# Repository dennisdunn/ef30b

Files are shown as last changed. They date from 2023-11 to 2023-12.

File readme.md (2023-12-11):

# EF-30B-disp Driver
This project repurposes a blown **EF-30B-disp** display board taken from
an electric fireplace as an I2C-addressable panel. The panel
consists of five LEDs and a two digit, 7-segment module. 

The original, blown, driver chip on the display board was
removed and replaced with 2, 8-pin, male headers. The four pin
interface socket was replaced with a 4-pin, right-angled, male
header.

The 8-pin headers connect with 2, 8-pin, female headers on 
a perfboard carrying a Raspberry Pi Pico MCU. The Pico is running
MicroPython.

When discussing pin numbers, the device is oriented so that the digits are upright and pin 1 is towards the top of the panel.

## Connecting the Panel
The 4-pin header connects power and the I2C bus to the panel. 

Pin|Function
---|---
1|VSYS
2|GND
3|SDA
4|SCL

## I2C Protocol
Querying or setting the registers is a two step process. First, write the register number to the device. Next, the controller writes a value to set the register or initiates a read to read the registers current value.

Register|Name
--------|----
0|Displayed value
1|Green LED
2|Yellow LED
3|Red LED #1
4|Red LED #2
5|Blue LED

### Selecting the I2C address
On the right side of the carrier board is a 3-pin header. Moving the jumper selects one of two device addresses.

Jumper Position|Selected Address
---|---
1-2|0x42
2-3|0x62

## ef30b Tool
The `bin/` folder contains a bash shell script to send commands to the device. It depends on the `i2c-tools` package.
 
 ```bash
 e30b <device_addr> <cmd> [subcmd]
 ```

 Command|Subcommand
 ---|---
 show|number between 0-99
 read|
 green|on, off, read
 yellow|on, off, read
 red1|on, off, read
 red2|on, off, read
 blue|on, off, read

## Display Board Notes
The **EF-30B-disp** circuit board is divided into a set of seven, common cathode, segments
and three chip select lines. When CS_0 is low, the seven segments of digit 0 (MSB)
are connected to ground and light up. When CS_1 is low, digit 1 (LSB) is enabled and 
when CS_2 is low, the LEDs are enabled. The LEDs are connected to segments A,B,C,D,E, and G.

## References
[I2CResponder](https://github.com/epmoyer/I2CResponder)

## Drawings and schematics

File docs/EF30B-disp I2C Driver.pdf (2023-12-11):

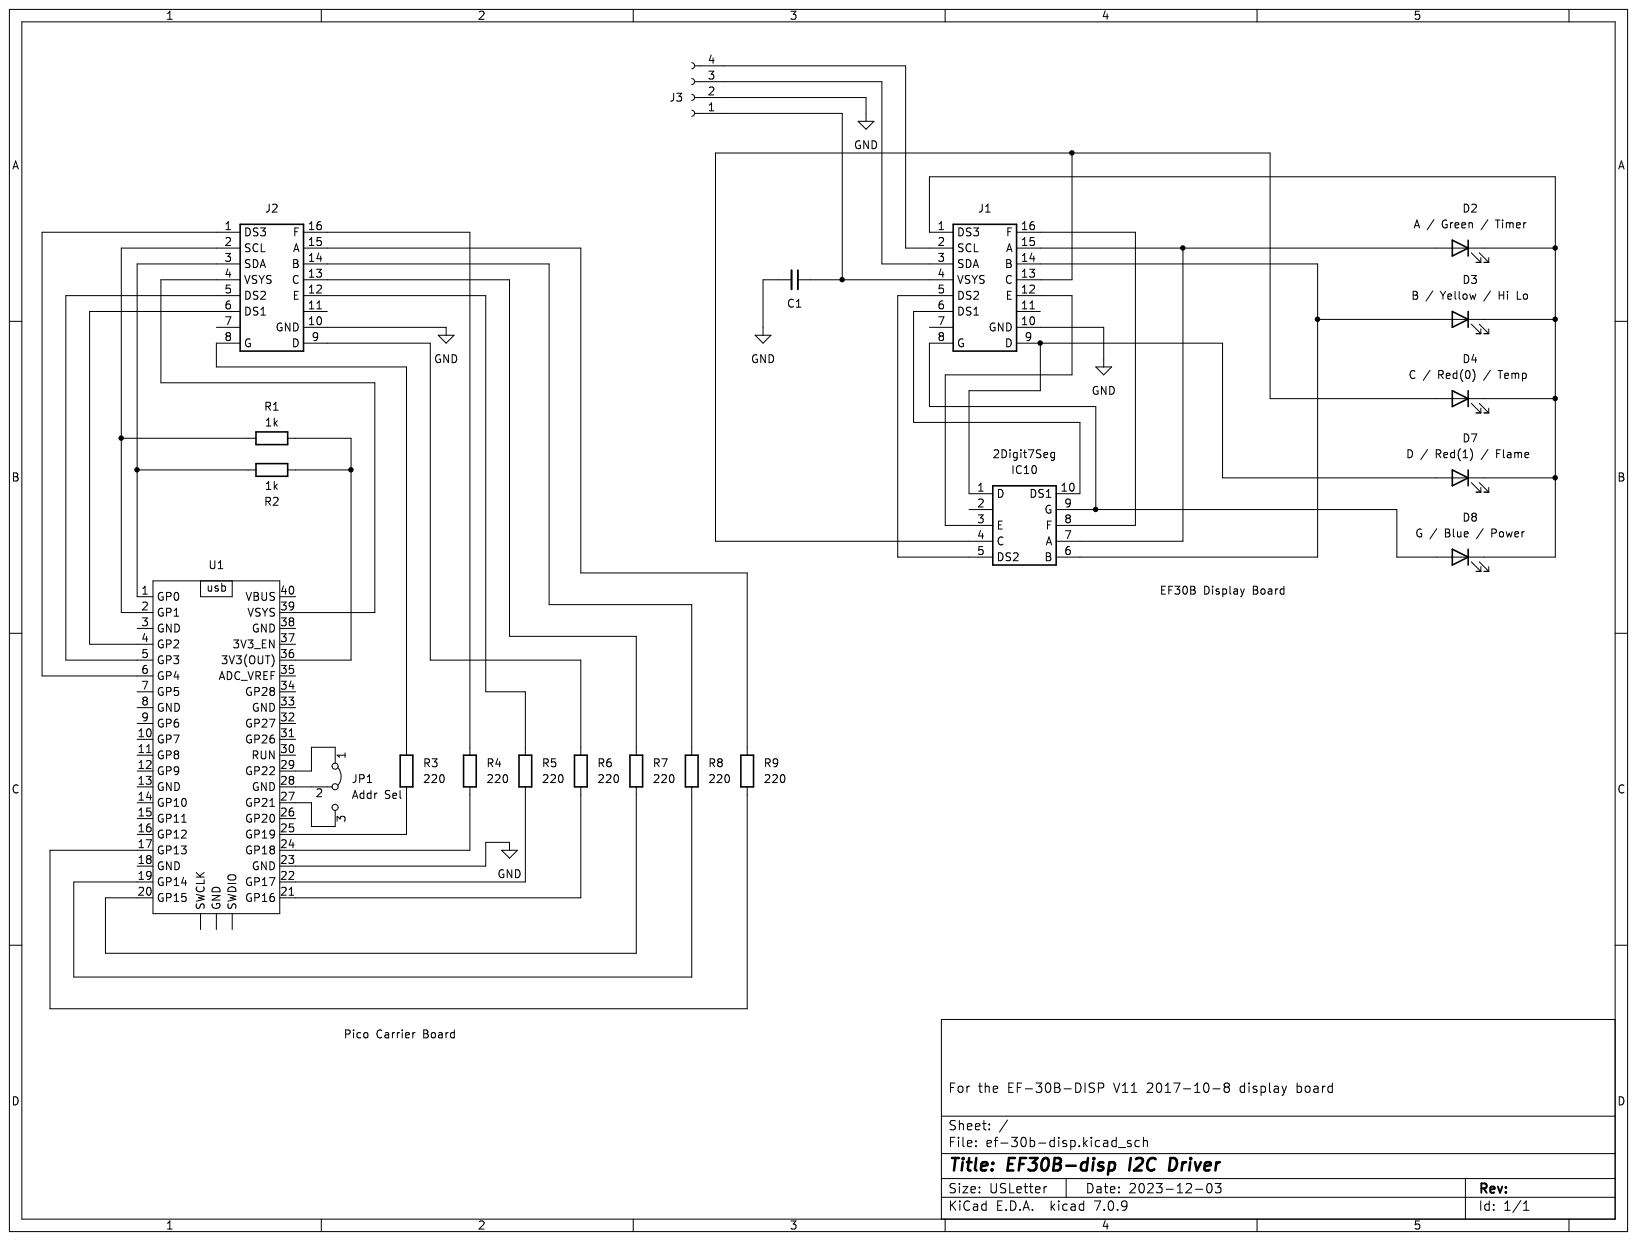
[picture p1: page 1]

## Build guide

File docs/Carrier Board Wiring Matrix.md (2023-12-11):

# Carrier Board Wiring Matrix

J2 Pin|U1 Pin|GPIO|Function
----------|----------|----------|----------|
1|6|4|DS3
2|2|1|SCL
3|1|0|SDA
4|39||VSYS
5|5|3|DS2
6|4|2|DS1
7|||
8|25|19|G
9|21|16|D
10|23||GND
11|||
12|22|17|E
13|20|15|C
14|19|14|B
15|17|13|A
16|24|18|F

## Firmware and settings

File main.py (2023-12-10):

import machine
import asyncio
from lib.lut import LookupTable
from lib.raspi import PinSet,Selector
from lib.display import Display
from lib.register import AsyncRegisters,Register
from lib.protocol import Protocol

I2C_ADDR_A = 0x42
I2C_ADDR_B = 0x62

def getI2cAddr():
    pin_a = machine.Pin(22,mode=machine.Pin.IN, pull=machine.Pin.PULL_UP)
    pin_b = machine.Pin(21,mode=machine.Pin.IN, pull=machine.Pin.PULL_UP)
    if not pin_a.value():
        return I2C_ADDR_A
    elif not pin_b.value():
        return I2C_ADDR_B
    else:
        raise Exception("Can't determine I2C device address.")
    
async def main():
    
    display = Display({
        Display.REGISTERS:AsyncRegisters(),
        Display.PINS:PinSet.create(13,14,15,16,17,18,19),
        Display.SELECTORS:Selector.create(2,3,4),
        Display.SEGMENT_LUT:LookupTable.create()
    })

    protocol = Protocol({
        Protocol.I2C_ADDR: getI2cAddr(),
        Protocol.REGISTER: display.context[Display.REGISTERS]
    })

    tasks = [display.start(1/120), protocol.start(0.50)]

    while True:
        await asyncio.sleep(0)

if __name__ == '__main__':
    try:
        asyncio.run(main())
    except KeyboardInterrupt:
        pass

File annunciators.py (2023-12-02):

import asyncio
import machine
from multiplexer import Mux

class Blinker(Mux):
    def __init__(self, pin):
        super().__init__({})
        self._pin = pin

    async def tick(self):
        self._pin.toggle()

async def main():
    b = Blinker(machine.Pin(25,machine.Pin.OUT))
    b.start(delay=0.2)    
    while True:
        await asyncio.sleep(0)

if __name__ == "__main__":
    try:
        asyncio.run(main())
    except Exception as e:
        print(e)
    finally:
        machine.reset()

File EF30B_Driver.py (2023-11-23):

from machine import Pin, Timer

class DigitSelect:
    def __init__(self, gpio) -> None:
        self.__pin = Pin(gpio, Pin.OPEN_DRAIN, value=1)
        
    def enabled(self, enabled=None):
        if enabled == None:
            return not self.__pin.value()
        else:
            self.__pin.value(not enabled)
            
    def enable(self):
        self.enabled(True)
            
    def disable(self):
        self.enabled(False)
        
    
class Segment:
    def __init__(self, gpio) -> None:
        self.__pin = Pin(gpio, Pin.OUT)
            
    def value(self, value=None):
        if value == None:            
            return self.__pin.value()
        else:
            self.__pin.value(value)
        
    def on(self):
        self.value(True)
        
    def off(self):
        self.value(False)
        
    def toggle(self):
        if self.value():
            self.off()
        else:
            self.on()
            
class SegmentController:
    def __init__(self, *segments) -> None:
        self.__segments = segments
        self.__lookup = [[1,1,1,1,1,1,0],
                         [0,1,1,0,0,0,0],
                         [1,1,0,1,1,0,1],
                         [1,1,1,1,0,0,1],
                         [0,1,1,0,0,1,1],
                         [1,0,1,1,0,1,1],
                         [0,0,1,1,1,1,1],
                         [1,1,1,0,0,0,0],
                         [1,1,1,1,1,1,1],
                         [1,1,1,0,0,1,1]]
        
    def update(self, n):
        if n < 0:
            for i in range(7):
                self.__segments[i].value(0)
        else:
            for i in range(7):
                self.__segments[i].value(self.__lookup[n][i])         

class MultipleDigitDisplay:
    def __init__(self, segmentController, *digitSelectors):
        self.__controller = segmentController
        self.__selectors = digitSelectors
        self.__values = [-1]*len(digitSelectors)
        self.__timer = Timer()
            
    def value(self, value):
        values = [-1]*len(self.__selectors) + [int(d) for d in str(value)]
        values.reverse()
        end=len(self.__selectors)
        values = values[0:end] 
        values.reverse()
        self.__values = values
            
    def on(self):
        
        def update(timer):
            for display,value in zip(self.__selectors,self.__values):
                self.__controller.update(value)
                display.enable()
                time.sleep(1/100)
                display.disable()
                
        for display in self.__selectors:
            display.enabled(True)
            
        self.__timer.init(mode=Timer.PERIODIC, freq=100, callback=update)
    
    def off(self):
        for display in self.__selectors:
            display.enabled(False)
        self.__timer.deinit()
        
    def clear(self):
        self.off()
               
    
DS1 = DigitSelect(2)
DS2 = DigitSelect(3)
DS3 = DigitSelect(4)

segments = SegmentController(Segment(13),Segment(14),Segment(15),Segment(16),Segment(17),Segment(18),Segment(19))

disp = MultipleDigitDisplay(segments, DS1, DS2)

disp.on()
while(True):
    for i in range(1,50):
        disp.value(i)
        time.sleep(0.1)
disp.off()

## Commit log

2023-11-27 It's working with digits and the led panel.
2023-11-29 Added the i2c responder class. Thank you https://github.com/epmoyer/I2CResponder.
2023-12-03 Added schematics for the Pi Pico daughterboard.
    [ef-30b-disp.kicad_sch]
2023-12-03 Updated the schematic.
    [ef-30b-disp.kicad_sch]
2023-12-06 Added schematic, wiring documentation.
    [EF30B Display Daughterboard Wiring Matrix.ods, ef-30b-disp.kicad_sch]
2023-12-06 Added the complete kicad project.
    [ef-30b-disp.kicad_pcb, ef-30b-disp.kicad_sch]
2023-12-06 Removed the kicad backups.
2023-12-07 Updated the wiring matrix.
    [EF30B Display Daughterboard Wiring Matrix.ods]
2023-12-09 Added i2c address selection code.
2023-12-10 Added a bash script to show numbers on the 7-segment displays and turn the LEDs on and off.
2023-12-10 Added an 'led read state' command to ef30b.
2023-12-11 Added jumpers to the board for VSYS and GND. Updated the shcematic and wiring table.
    [ef-30b-disp.kicad_sch]
